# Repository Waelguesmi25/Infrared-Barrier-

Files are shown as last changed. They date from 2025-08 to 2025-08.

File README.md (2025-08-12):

# 🌐 Infrared Barrier Project  

## 📌 Overview  
This repository contains the design files for an **Infrared Barrier system** that detects interruptions in an infrared beam and processes them for counting or triggering events.  
The project was developed for educational purposes, focusing on a compact and adaptable design.  

## ✨ Features  
* Detects objects passing through an infrared beam.  
* Counts and displays events in real time.  
* Visual and/or audible indicators for detections.  
* Adjustable timing and sensitivity.  
* PCB layout and schematic ready for fabrication.  

## 📂 Repository Contents  
* **barriere_IR.sch** – Schematic file (circuit design).  
* **barriere_IR.brd** – PCB layout file (board design).  
* **schéma_de_routage.pdf** – Routing diagram.  
* **schéma_d'implantation.pdf** – Component placement diagram.  
* **TYPON.pdf** – PCB mask for manufacturing or DIY etching.  
* **barriere_IR.s## / barriere_IR.s#1** – Backup schematic versions.  

## 🛠 Usage  
1. **Open & Edit** → Use *Autodesk Eagle* to view or modify the schematic and PCB files.  
2. **Fabricate PCB** → Generate Gerber files or use the provided PDF mask for DIY etching.  
3. **Assemble** → Follow the placement diagram for soldering components.  
4. **Test & Calibrate** → Power the system, test beam interruption detection, and adjust sensitivity if needed.  

## 📜 License  
*Open-source under the **MIT License*** – free to use, modify, and adapt for personal or educational purposes.  

**👤 Author:** *Wael Guesmi*

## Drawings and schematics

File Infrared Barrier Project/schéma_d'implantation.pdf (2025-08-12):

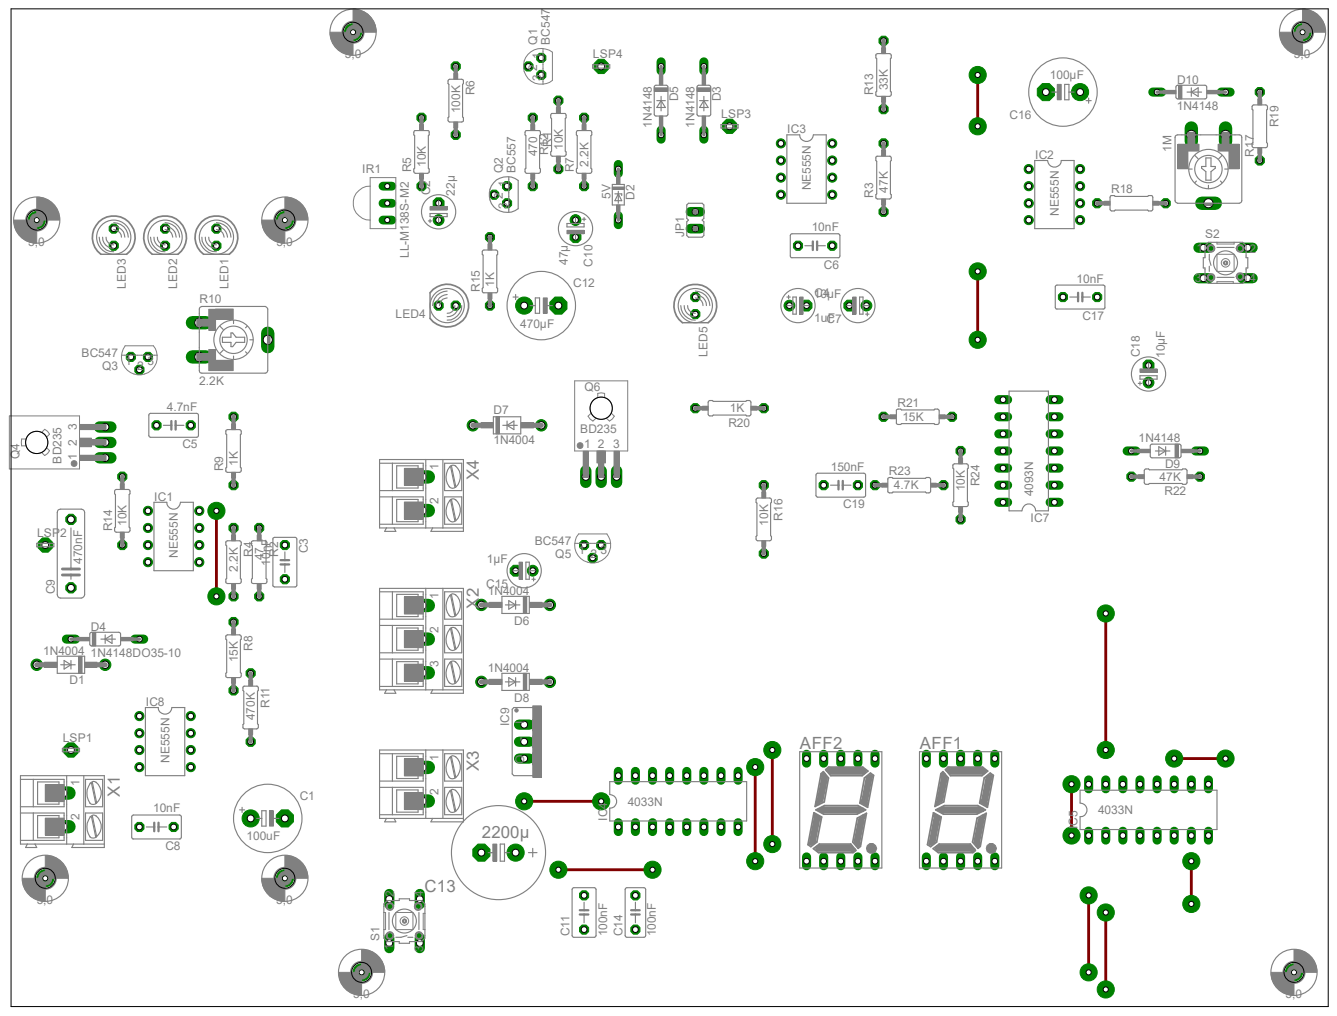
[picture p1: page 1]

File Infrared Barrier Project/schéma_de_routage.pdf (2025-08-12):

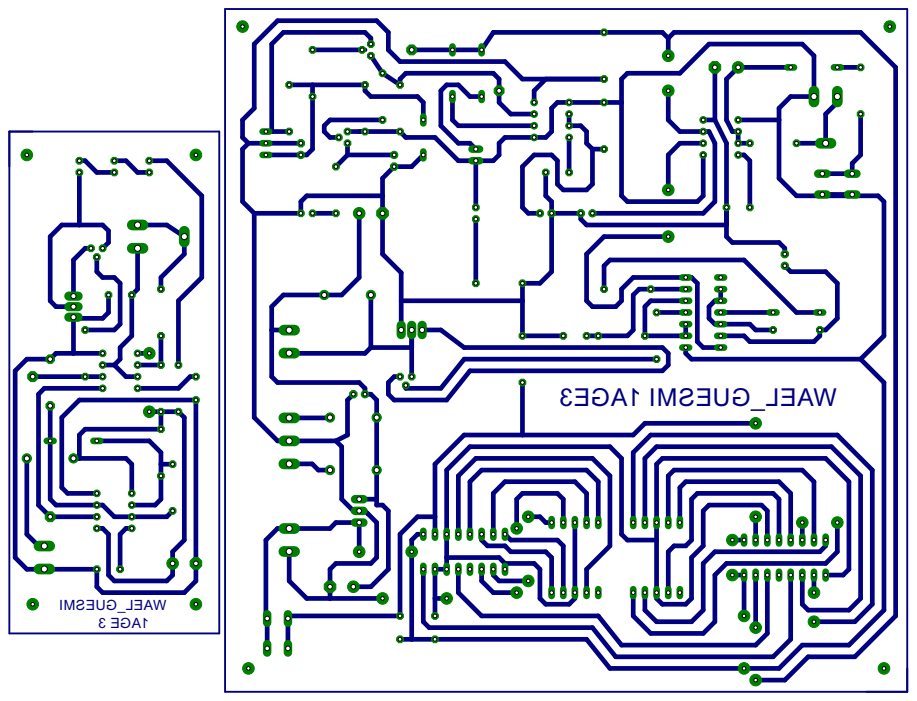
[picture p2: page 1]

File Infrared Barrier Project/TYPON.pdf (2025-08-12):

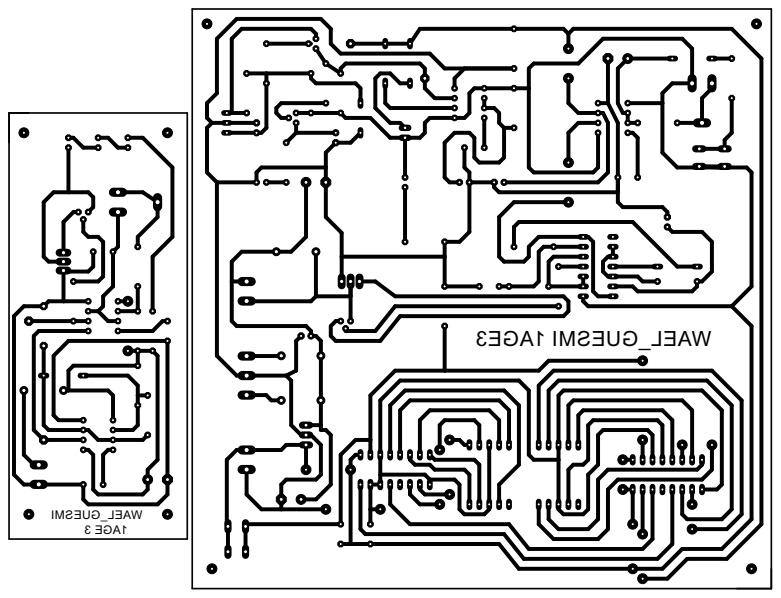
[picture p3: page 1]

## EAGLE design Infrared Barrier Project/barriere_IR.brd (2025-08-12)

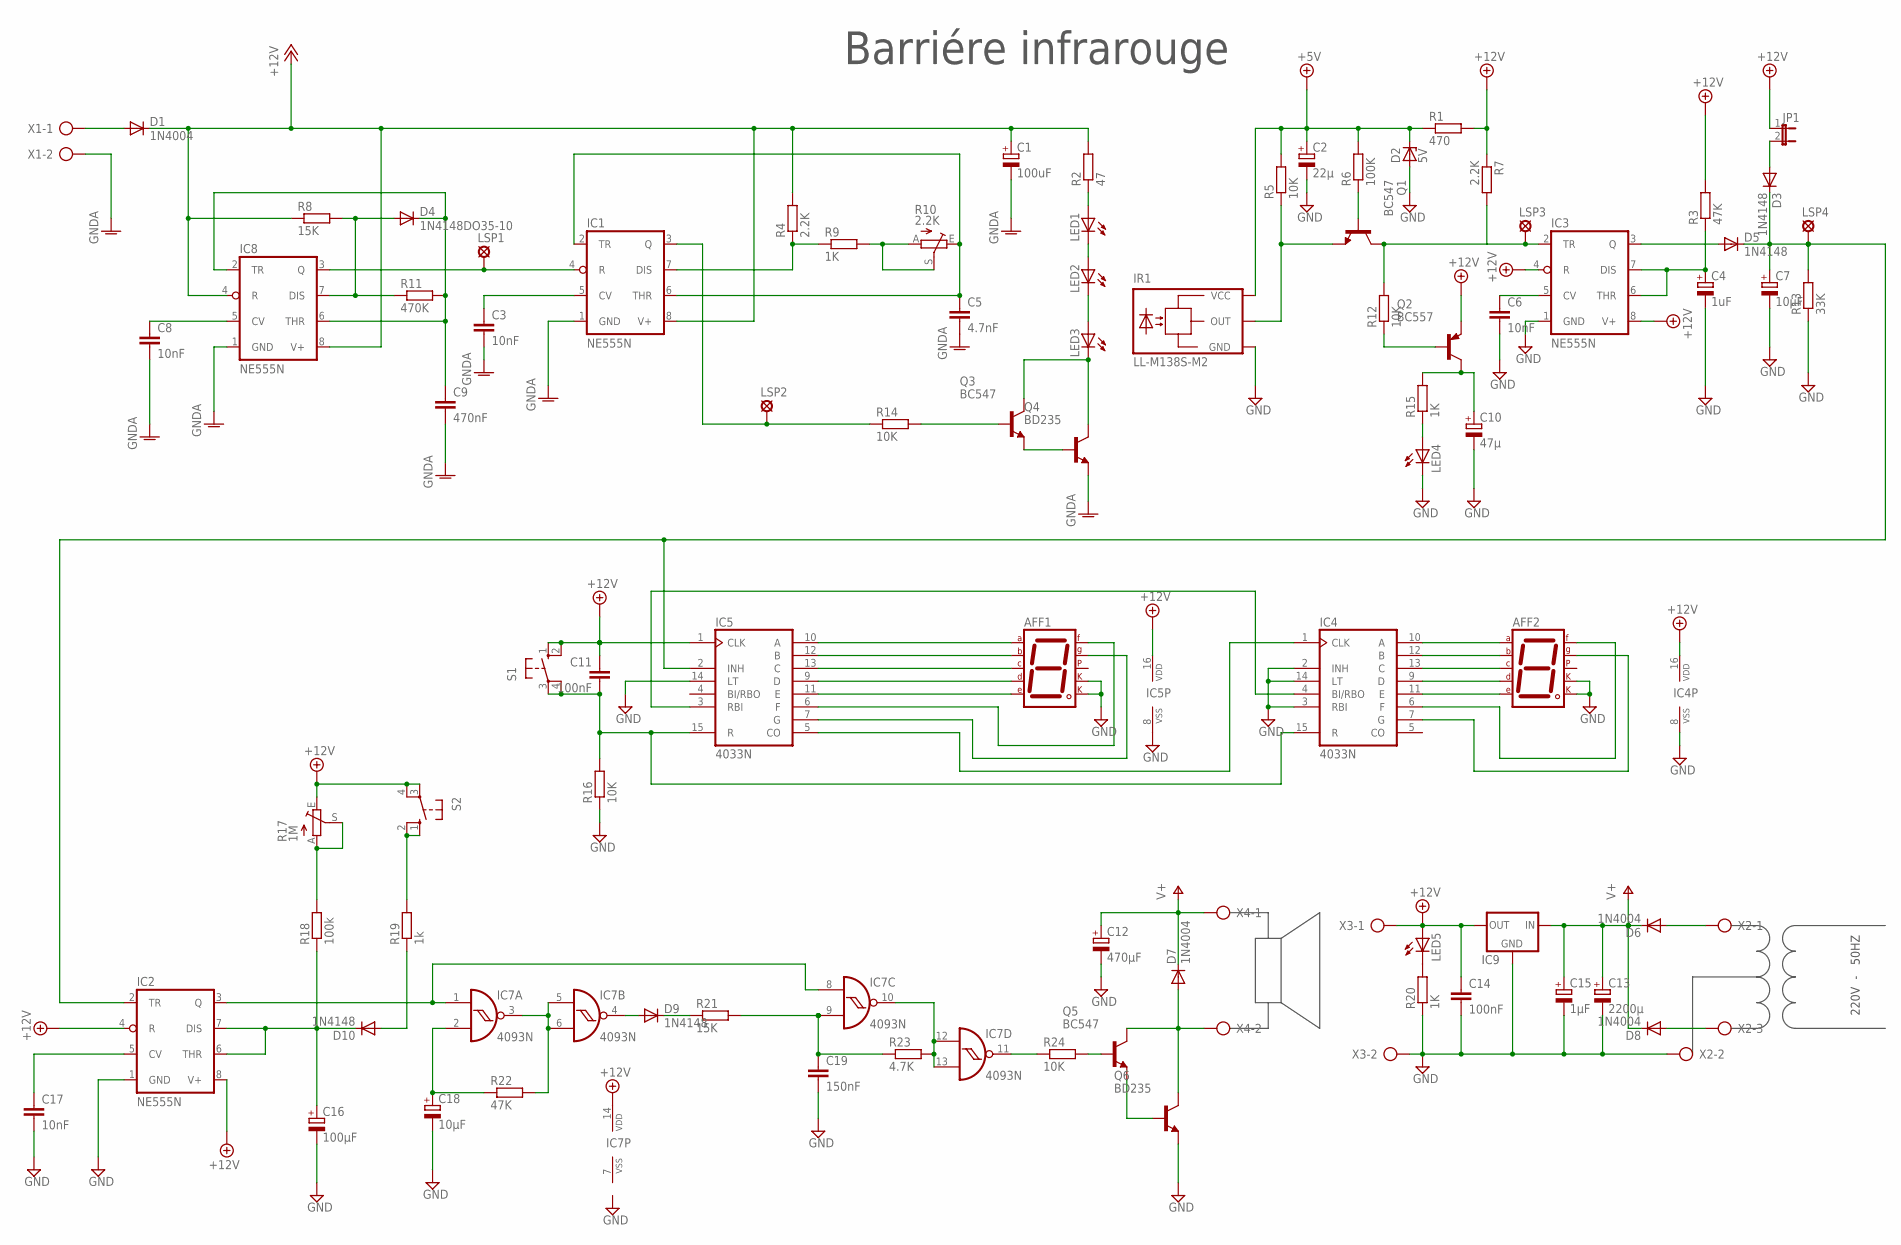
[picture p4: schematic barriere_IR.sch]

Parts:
AFF1, AFF2: 7SEG-CK; 7SEG-13
C1: 100uF; E5-10,5
C2: 22µ; E2,5-5
C3, C6, C8, C17: 10nF; C050-035X075
C4: 1uF; E2,5-5
C5: 4.7nF; C050-035X075
C7, C18: 10µF; E2,5-5
C9: 470nF; C102-043X133
C10: 47µ; E2,5-5
C11: 100nF; C050-035X075
C12: 470µF; E5-10,5
C13: 2200µ; E5-13
C14: 100nF; C050-030X075
C15: 1µF; E2,5-5
C16: 100µF; E5-10,5
C19: 150nF; C050-035X075
D1, D6, D7, D8: 1N4004; DO41-10
D2: 5V; DO34Z7
D3, D5, D9, D10: 1N4148; DO35-10
D4: 1N4148DO35-10; DO35-10
IC1, IC2, IC3, IC8: NE555N; DIL08
IC4, IC5: 4033N; DIL16
IC7: 4093N; DIL14
IC9: 78XXS
IR1: LL-M138S-M2
JP1: JP1E; JP1
LED1, LED2, LED3, LED4, LED5: LED5MM
LSP1, LSP2, LSP3, LSP4: LSP10
Q1, Q3, Q5: BC547; TO92
Q2: BC557; TO92
Q4, Q6: BD235; TO126
R1: 470; 0207/10
R2: 47; 0207/10
R3, R22: 47K; 0207/10
R4, R7: 2.2K; 0207/10
R5, R12, R14, R16, R24: 10K; 0207/10
R6: 100K; 0207/10
R8, R21: 15K; 0207/10
R9, R15, R20: 1K; 0207/10
R10: 2.2K; CA9V
R11: 470K; 0207/10
R13: 33K; 0207/10
R17: 1M; CA9V
R18: 100k; 0207/10
R19: 1k; 0207/10
R23: 4.7K; 0207/10
S1, S2: 10-XX; B3F-10XX
X1, X3, X4: AK300/2
X2: AK300/3

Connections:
+5V: C2.+, D2.C, IR1.3 (VCC), R1.1, R5.2, R6.2
+12V: C11.1, C14.1, IC2.4 (R), IC2.8 (V+), IC3.4 (R), IC3.8 (V+), IC4.16 (VDD), IC5.1 (CLK), IC5.16 (VDD), IC7.14 (VDD), IC9.OUT, JP1.1, LED5.A, Q2.1 (E), R1.2, R3.2, R7.1, R17.E, S1.1 (S), S1.2 (S1), S2.3, S2.4 (P1), X3.1
+12V/1: C1.+, D1.C, IC1.8 (V+), IC8.4 (R), IC8.8 (V+), R2.2, R4.2, R8.1
GND: AFF1.3 (CK1), AFF1.8 (CK2), AFF2.3 (CK1), AFF2.8 (CK2), C2.-, C4.-, C6.2, C7.-, C10.-, C12.-, C13.-, C14.2, C15.-, C16.-, C17.2, C18.-, C19.2, D2.A, IC2.1 (GND), IC3.1 (GND), IC4.2 (INH), IC4.3 (RBI), IC4.8 (VSS), IC4.14 (LT), IC5.8 (VSS), IC5.14 (LT), IC9.GND, IR1.2 (GND), LED4.K (C), Q6.1 (E), R13.1, R16.1, R20.1, X2.2, X3.2
GNDA: C1.-, C3.2, C5.2, C8.2, C9.2, IC1.1 (GND), IC8.1 (GND), Q4.1 (E), X1.2
unnamed: D1.A, X1.1
unnamed: D4.A, IC8.7 (DIS), R8.2, R11.1
unnamed: IC1.3 (Q), LSP2.MP, R14.1
unnamed: C9.1, D4.C, IC8.2 (TR), IC8.6 (THR), R11.2
unnamed: IC1.4 (R), IC8.3 (Q), LSP1.MP
unnamed: C3.1, IC1.5 (CV)
unnamed: IC1.7 (DIS), R4.1, R9.1
unnamed: C8.1, IC8.5 (CV)
unnamed: R9.2, R10.A, R10.S
unnamed: IR1.1 (OUT), Q1.1 (E), R5.1
unnamed: C5.1, IC1.2 (TR), IC1.6 (THR), R10.E
unnamed: C6.1, IC3.5 (CV)
unnamed: LED1.A, R2.1
unnamed: LED1.K (C), LED2.A
unnamed: LED2.K (C), LED3.A
unnamed: LED3.K (C), Q3.3 (C), Q4.2 (C)
unnamed: Q3.1 (E), Q4.3 (B)
unnamed: Q3.2 (B), R14.2
unnamed: C4.+, IC3.6 (THR), IC3.7 (DIS), R3.1
unnamed: D5.A, IC3.3 (Q)
unnamed: IC3.2 (TR), LSP3.MP, Q1.3 (C), R7.2, R12.2
unnamed: Q1.2 (B), R6.1
unnamed: C7.+, D3.C, D5.C, IC2.2 (TR), IC5.2 (INH), LSP4.MP, R13.2
unnamed: D3.A, JP1.2
unnamed: Q2.2 (B), R12.1
unnamed: C10.+, Q2.3 (C), R15.2
unnamed: C11.2, IC4.15 (R), IC5.15 (R), R16.2, S1.3, S1.4 (P1)
unnamed: LED4.A, R15.1
unnamed: AFF1.7 (A), IC5.10 (A)
unnamed: AFF1.6 (B), IC5.12 (B)
unnamed: AFF1.4 (C), IC5.13 (C)
unnamed: AFF1.2 (D), IC5.9 (D)
unnamed: AFF1.1 (E), IC5.11 (E)
unnamed: AFF1.9 (F), IC5.6 (F)
unnamed: AFF1.10 (G), IC5.7 (G)
unnamed: IC4.1 (CLK), IC5.5 (CO)
unnamed: C17.1, IC2.5 (CV)
unnamed: AFF2.7 (A), IC4.10 (A)
unnamed: IC4.4 (BI/RBO), IC5.3 (RBI)
unnamed: AFF2.6 (B), IC4.12 (B)
unnamed: AFF2.4 (C), IC4.13 (C)
unnamed: AFF2.2 (D), IC4.9 (D)
unnamed: AFF2.1 (E), IC4.11 (E)
unnamed: AFF2.9 (F), IC4.6 (F)
unnamed: AFF2.10 (G), IC4.7 (G)
unnamed: C16.+, D10.C, IC2.6 (THR), IC2.7 (DIS), R18.1
unnamed: R19.2, S2.1 (S), S2.2 (S1)
unnamed: R17.A, R17.S, R18.2
unnamed: D10.A, R19.1
unnamed: C18.+, IC7.2 (I1), R22.1
unnamed: IC2.3 (Q), IC7.1 (I0), IC7.8 (I0)
unnamed: IC7.3 (O), IC7.5 (I0), IC7.6 (I1), R22.2
unnamed: D9.A, IC7.4 (O)
unnamed: D9.C, R21.1
unnamed: C19.1, IC7.9 (I1), R21.2, R23.1
unnamed: IC7.10 (O), IC7.12 (I0), IC7.13 (I1), R23.2
unnamed: IC7.11 (O), R24.1
unnamed: Q5.2 (B), R24.2
unnamed: Q5.1 (E), Q6.3 (B)
unnamed: D7.A, Q5.3 (C), Q6.2 (C), X4.2
unnamed: LED5.K (C), R20.2
unnamed: D8.A, X2.3
unnamed: D6.A, X2.1
V+: C12.+, C13.+, C15.+, D6.C, D7.C, D8.C, IC9.IN, X4.1
VSS: IC7.7 (VSS)

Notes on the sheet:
220V - 50HZ
Barriére infrarouge

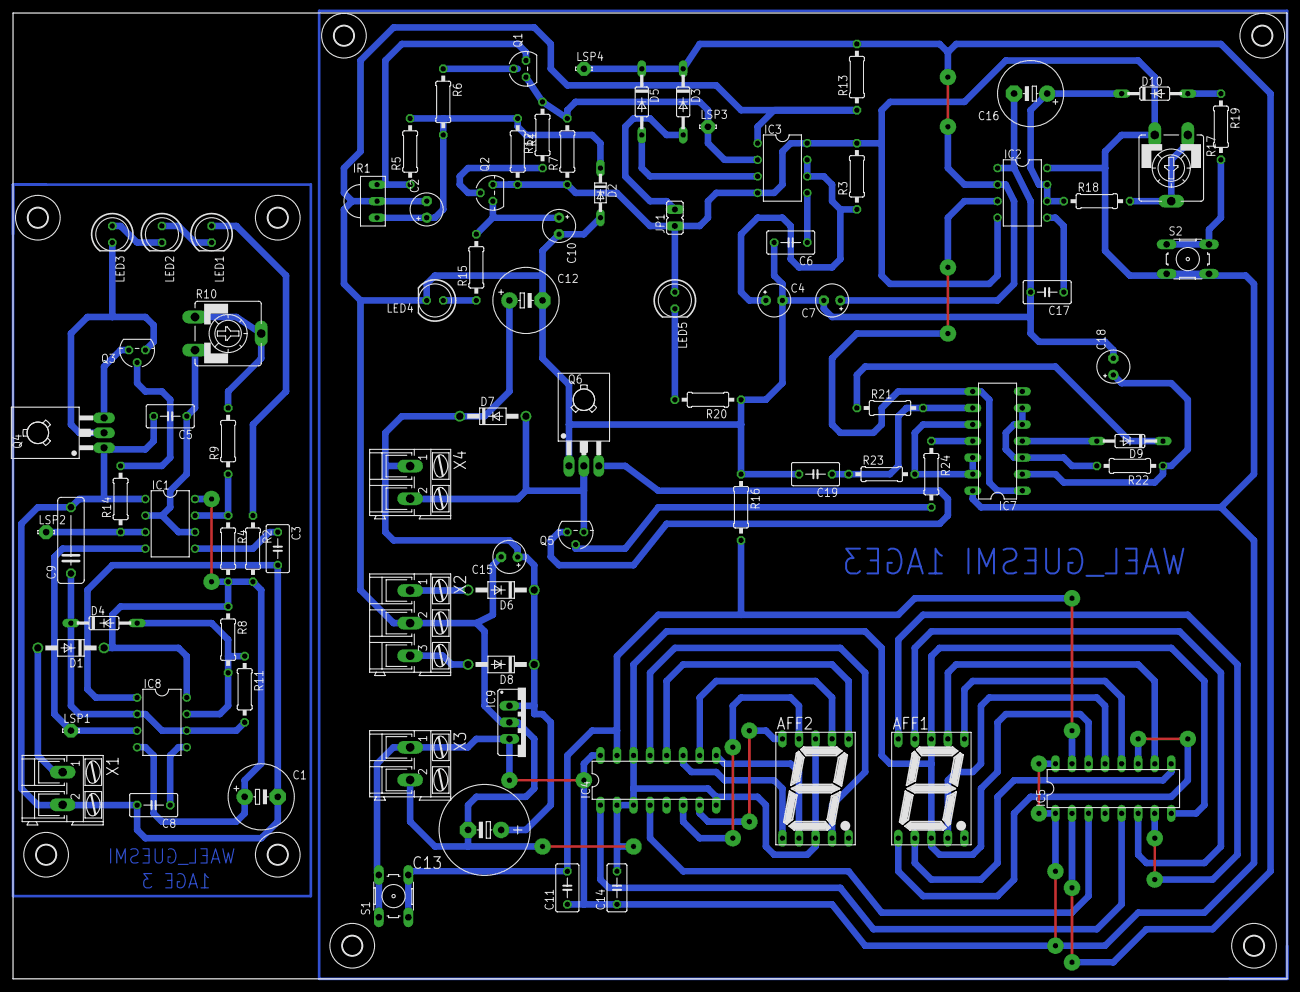
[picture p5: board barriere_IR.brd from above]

Board: 2 copper layers, 195.6 x 148.3 mm, 94 parts (0 on the bottom side), 69 nets.

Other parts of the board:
U$1, U$2, U$3, U$4, U$5, U$6, U$7, U$8: 3,0
